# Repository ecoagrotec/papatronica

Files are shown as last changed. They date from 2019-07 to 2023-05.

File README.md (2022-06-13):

# papatronica

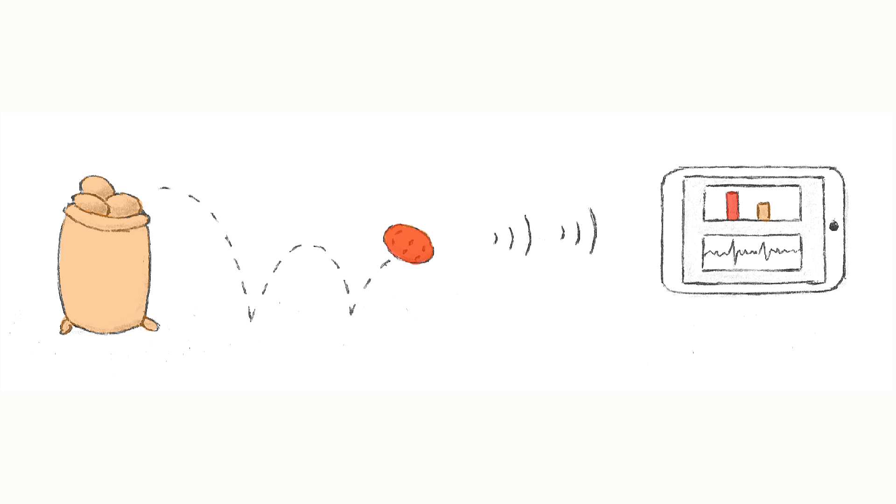
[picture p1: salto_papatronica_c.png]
papatronica


**papatronica** es un dispositivo abierto y modular diseñado para ser utilizado en el proceso de producción, cosecha, industrialización, comercialización y distribución de papa y con posible aplicación también en otros frutos y hortalizas. 

El objetivo general de Papatronica es poner a disposición de pequeños y medianos productores así como de toda la cadena de valor de producción de papa ( y de vegetales y hortalizas en general) una plataforma abierta y modular de código abierto y bajo costo que permita determinar los procesos o puntos específicos dentro de un proceso, donde se producen golpes, daños mecánicos y condiciones ambientales que afecten el estado y la conservación de los productos. Esto disminuirá significativamente las pérdidas de productos que se producen después de la cosecha (aproximadamente del 35% de las frutas y hortalizas producidas).
Esta plataforma, en principio se desarrollará orientada al uso en el cultivo de papa, pero será fácilmente adaptable a otros cultivos o productos.
 
## Objetivos específicos: 

- Medir los golpes que reciben los productos durante la cosecha, traslado, almacenamiento y comercialización.

- Ajustar la configuración ideal de las máquinaria para una producción libre de golpes.

- Investigar en forma objetiva los motivos del daño del producto por fuerzas de impacto en maquinaria, traslado y almacenamiento.

- Registrar y documentar la información para el cumplimiento de los procedimientos de control de calidad.

- Mejorar el diseño de maquinaria identificando los niveles de impacto.

- Ayudar a los productores y asesores a configurar sus máquinas para evitar altos niveles de impacto.

- Investigar enfoques de manejo técnico que minimicen los niveles de impacto en las papas.

- Determinar los umbrales para el riesgo de daño a las papas debido a la fuerza de impacto

- Investigar diferentes materiales que podrían reducir el riesgo de daños a las papas

Los productores, las industrias, la cadena comercial y los consumidores serían beneficiarios directos de este dispositivo.

### Perspectivas a futuro: 
 “papatronica” podría medir y registrar desde la plantación; temperatura, humedad, conductividad eléctrica y ph en el suelo. Se cosechará junto con el resto del lote y registrará toda la información durante la cosecha, el traslado y el almacenamiento, donde también medirá CO2 (y posiblemente otros gases). También podría transmitir toda la información en tiempo real permitiendo un seguimiento permanente y en tiempo real de las condiciones de los tubérculos desde la plantación hasta el punto final de comercialización.

### Requerimientos funcionales y estructurales del prototipo básico:

- La carcasa externa debe ser de forma oval alargada (similar a una papa), con un tamaño aproximado de 10 cm de largo, 8 de ancho y 7 de espesor; y suficientemente resistente para soportar aproximadamente 100 Kg de presión y caídas de hasta 2 m de altura. 

- La carcasa debe ser hermética para evitar el ingreso de polvo y agua, pero a su vez, debe ser posible abrir la misma para modificar o reemplazar componentes.

- La carcasa debe contener todos los componentes del dispositivo en forma segura y firme; pero a su vez debe permitir que los mismos sean retirados o reemplazados.
 
- La información registrada por los sensores deberá ser enviada al dispositivo de lectura (celular o tablet) en tiempo real a una distancia de aproximadamente 10 m. 

- La información debe ser simplificada visualizada en forma  “amigable con el usuario”

## Roadmap
1. definir componentes
2. presupuestar: componentes, desarrollo de app, diseño y construcción
3. búsqueda de financiamiento
4. compra de materiales y armado de prototipos
5. pruebas de campo y validación

*actualmente estamos en las etapas 3, 4 y 5 (ver la lista de [tareas/issues](https://github.com/ecoagrotec/papatronica/issues))*

Este es un proyecto de hardware abierto y se aceptan todo tipo de sugerencias, aportes y contribuciones (por ejemplo respondiendo a alguno de los _['issues'](https://github.com/ecoagrotec/papatronica/issues)_, abriendo algún nuevo _issue_, o mandándonos un mail con tus comentarios). 

Participantes del proyecto: 
- Luciano Velázquez
- Gustavo Pereyra Irujo
- Franco Pérez
- José Marone
- Ignacio Lalloz

Contacto:
luchovelazquez@gmail.com
gpereyrairujo@gmail.com

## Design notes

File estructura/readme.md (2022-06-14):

## Estructura de la Papatrónica

La estructura está realizada mediante impresión 3D en polímero de Nylon 6, utilizando una temperatura de extrusión de 235 °C y una temperatura de la cama de impresión de 110 °C. Está diseñada en 2 mitades simétricas complementarias, con una placa en la parte media sobre la cual se sujetan los componentes; y unidas por tornillos con tuercas.

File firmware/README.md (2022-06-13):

Pasos para cargar el programa en la placa NodeMCU:
1. Descargar el archivo papatronica.ino
2. Instalar el software Arduino IDE (descargar de https://www.arduino.cc/en/Main/Software)
3. Instalar desde el repositorio las librerias de espressif (chequear si son estas: https://github.com/espressif/arduino-esp32/tree/master/libraries)
4. Conectar la placa mediante un cable USB
5. Enviar el programa a la placa, presionando a la vez el botón "IO0" de la placa

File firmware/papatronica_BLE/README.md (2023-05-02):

  Firmware Papatronica BLE 
  Para la siguiente configuración de hardware/software:
  - Placa Adafruit Feather Bluefruit LE -> Bluefruit LE Connect app
  - Sensor Adafruit ADXL375

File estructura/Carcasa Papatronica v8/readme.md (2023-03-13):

La unica modificacion con respecto a la version 7 es que esta version se puede imprimir sin soportes.
Para lograr esto se usan puentes de 4cm max, si la impresora que se usa no soporta puentes de ese tamaño se recomienda usar soportes.

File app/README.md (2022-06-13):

El prototipo inicial de interfaz para el usuario que se está utilizando para las pruebas de la Papatrónica se desarrolló usando la app Android "RoboRemoFree" (https://www.roboremo.com/), que permite conectarse mediante Bluetooth a la placa nodeMCU, y editar fácilmente los elementos a mostrar en la pantalla.

Instrucciones para instalar la app y la interfaz:
1. Descargar la última versión del archivo UI-papatronica en el teléfono, desde https://github.com/ecoagrotec/papatronica/tree/master/app
2. Instalar la aplicación "RoboRemoFree" desde el Play Store de Android
3. Abrir la app
4. Ir a menu > interface > import
5. Seleccionar el archivo UI-papatronica

Instrucciones para utilizar la app con la papatronica:
1. Abrir la app y encender la papatronica
2. Ir a menu > connect
3. Seleccionar de la lista a papatronica

Instrucciones para modificar la interfaz:
1. Ir a menu > edit ui
2. Hacer los cambios
3. Para guardar los cambios en un archivo ir a menu > interface > export

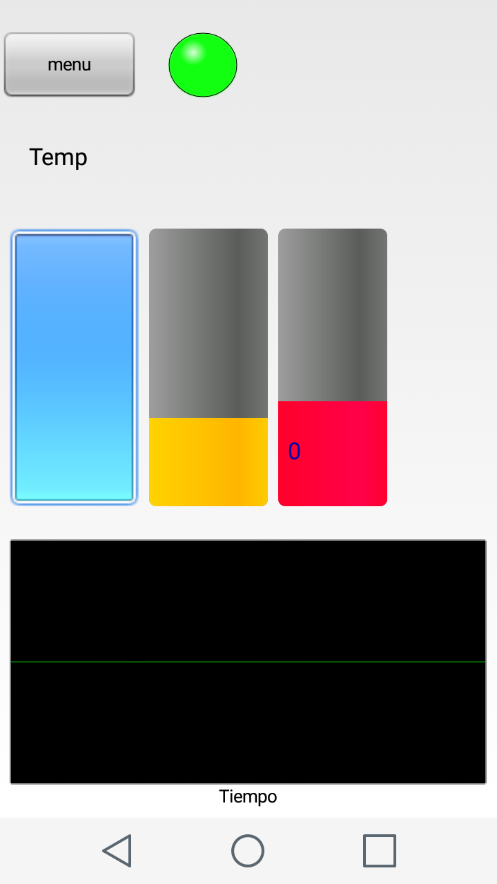
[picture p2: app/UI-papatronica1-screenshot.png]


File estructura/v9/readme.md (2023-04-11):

Esta nueva version esta echa en Fusion360. Ademas de los STLs subo el diseño completo y editable en Fusion360(.f3z). El tamaño del archivo .f3z es muy grande para github, estoy buscando alternativas para compartirlo.
Tiene algunos cambios menores con respecto a la v8.

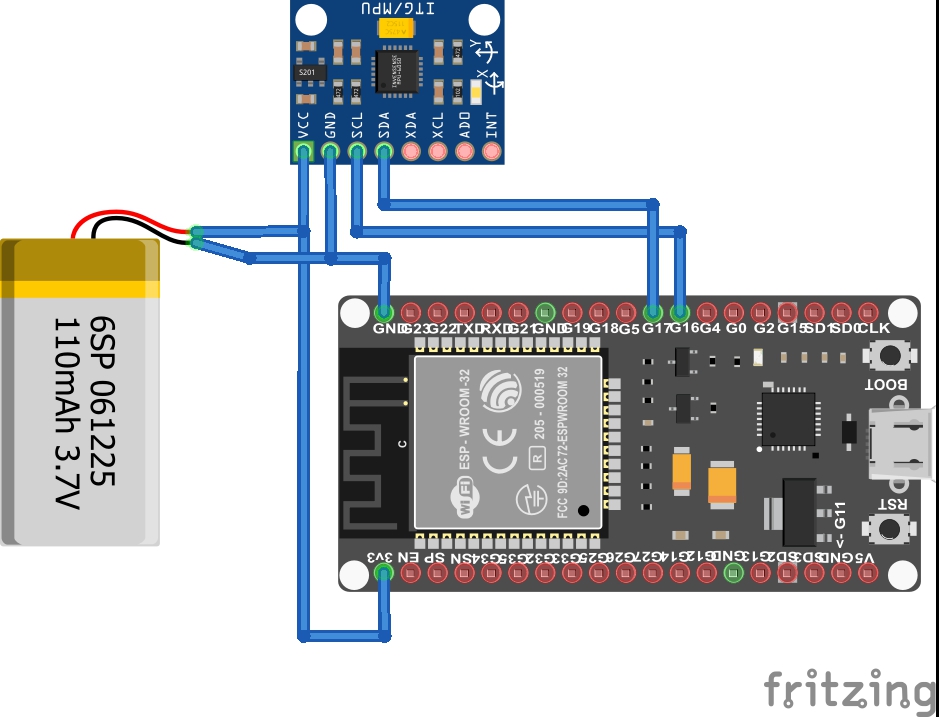
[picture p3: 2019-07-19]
electronica/papatronica.jpg

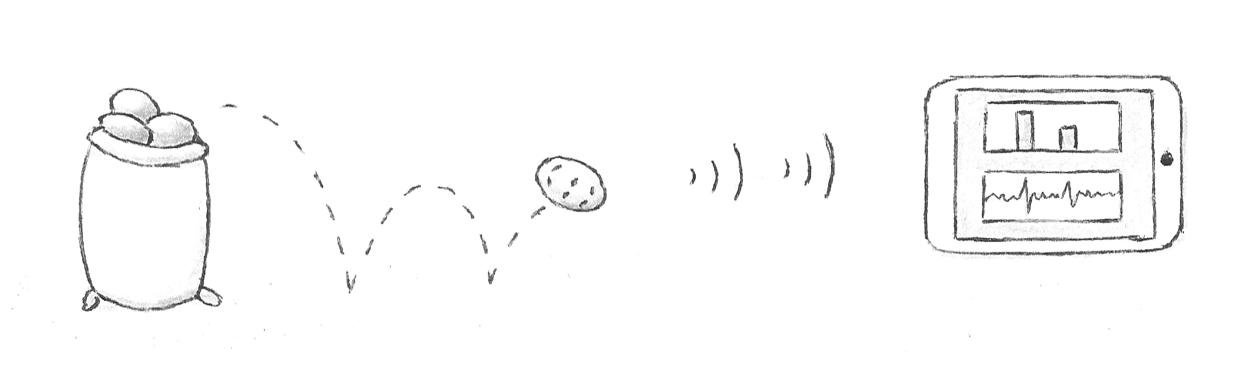
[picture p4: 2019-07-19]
salto_papatronica.png

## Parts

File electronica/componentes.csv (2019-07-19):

Componente | Nombre | Modelo
1 | Acelerómetro+giróscopo | MPU-6500
2 | Placa principal | NodeMCU Wifi+Bluetooth ESP32S
3 | Batería | Litio-Polímero 3.7V 500mAh

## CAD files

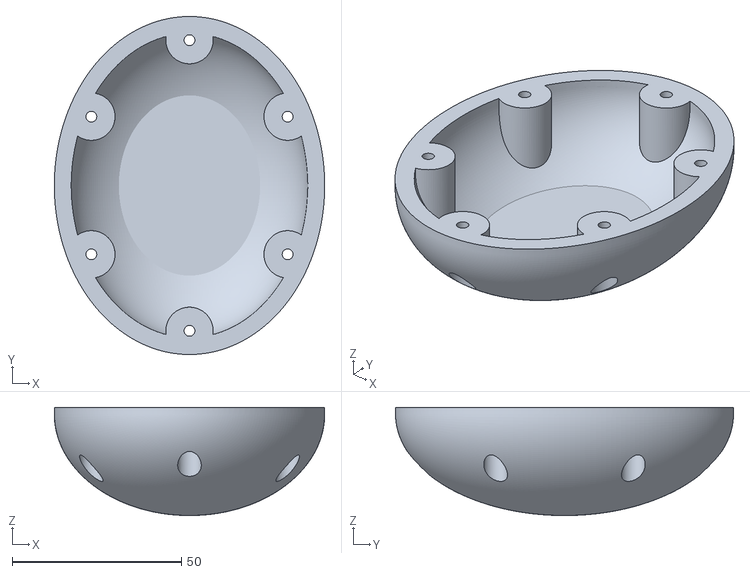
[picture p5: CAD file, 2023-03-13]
estructura/Carcasa Papatronica v8/v8 - Carcasa Papatronica - Mitad Tornillos.STL
80.0 x 100.0 x 32.0

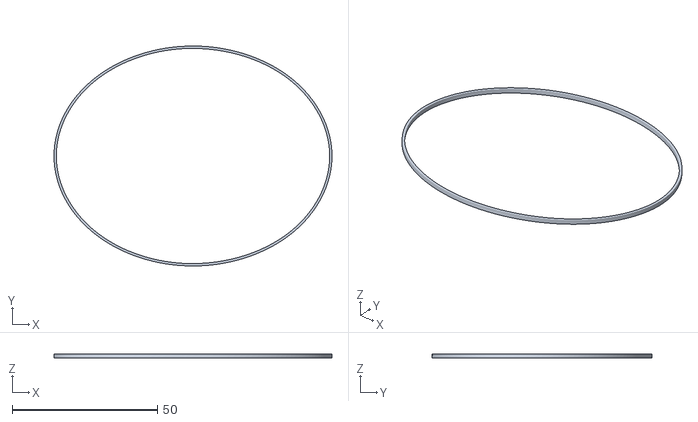
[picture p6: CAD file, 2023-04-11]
estructura/v9/Papatronica - Oring v9.stl
95.8 x 75.8 x 1.50

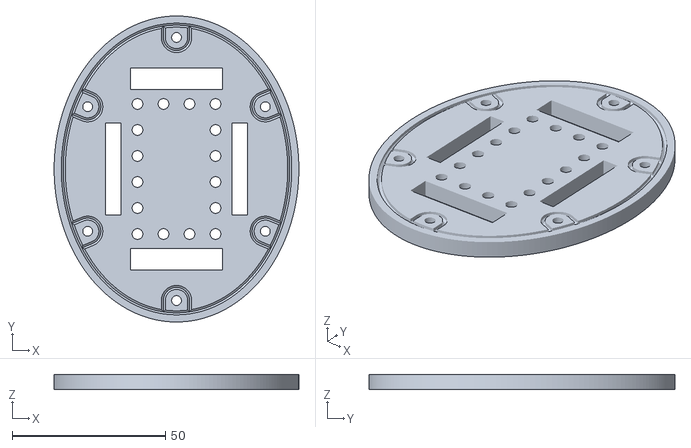
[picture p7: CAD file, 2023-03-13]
estructura/Carcasa Papatronica v8/v8 - Carcasa Papatronica - Rejilla.STL
80.0 x 100.0 x 5.00

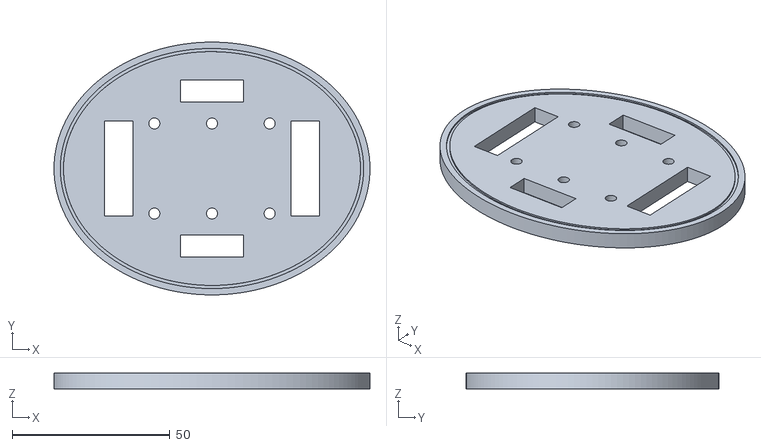
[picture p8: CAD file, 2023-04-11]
estructura/v9/Papatronica - Plate v9.stl
100.0 x 80.0 x 5.00

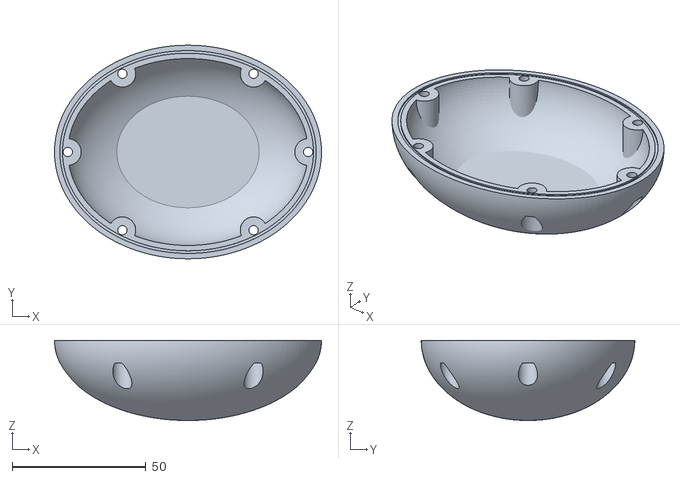
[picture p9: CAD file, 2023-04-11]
estructura/v9/Papatronica - Case-Bolt v9.stl
100.0 x 80.0 x 30.0

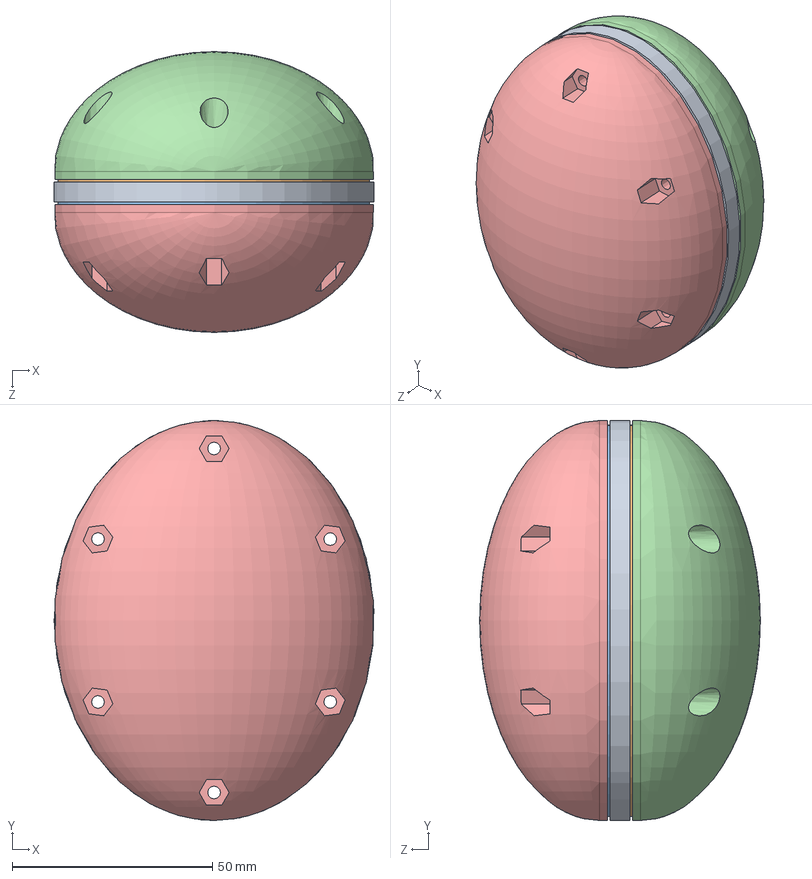
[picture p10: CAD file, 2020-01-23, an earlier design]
estructura/Carcasa Papatronica v7/v7 - Carcasa Papatronica - Ensamble Completo.SLDASM
79.9 x 100.0 x 70.2 mm
v7 - Carcasa Papatronica - Rejilla
v7 - Carcasa Papatronica - ORing
Copy of MirrorORing^v7 - Carcasa Papatronica - Ensamble Completo
v7 - Carcasa Papatronica - Mitad Tornillos
v7 - Carcasa Papatronica - Mitad Tuercas

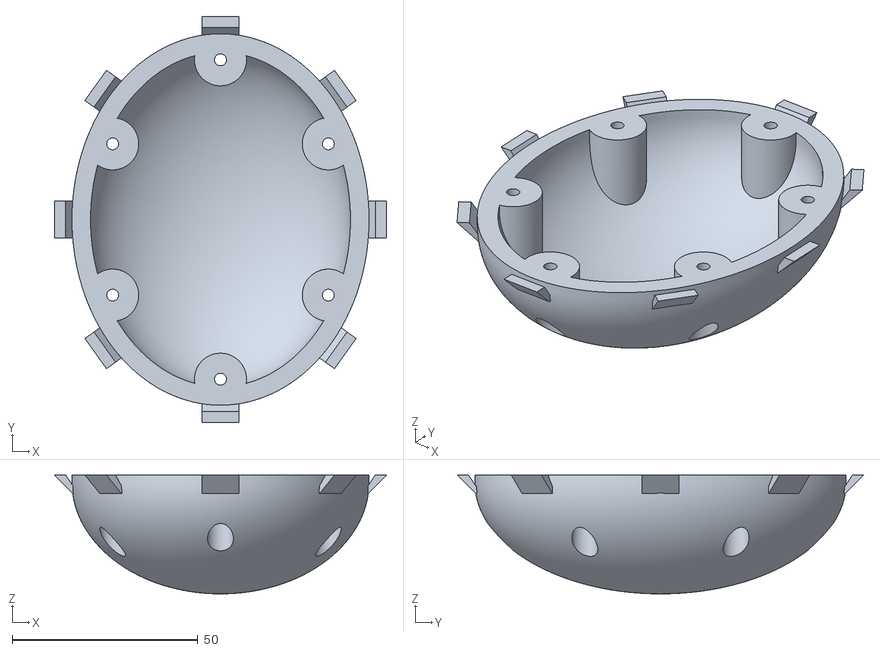
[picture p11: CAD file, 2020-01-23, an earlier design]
estructura/Carcasa Papatronica v7/STL y Gcode/v7 - Carcasa Papatronica - Mitad Tornillos.STL
89.4 x 109.4 x 32.0

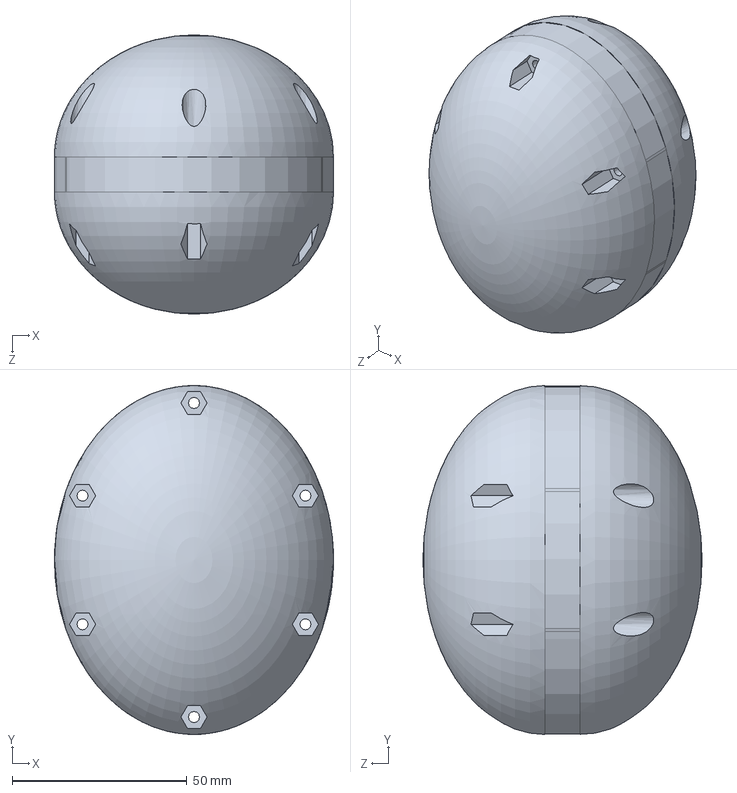
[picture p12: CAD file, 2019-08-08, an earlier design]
estructura/v5/Carcaza Papa.SLDPRT
80.0 x 100.0 x 80.0 mm

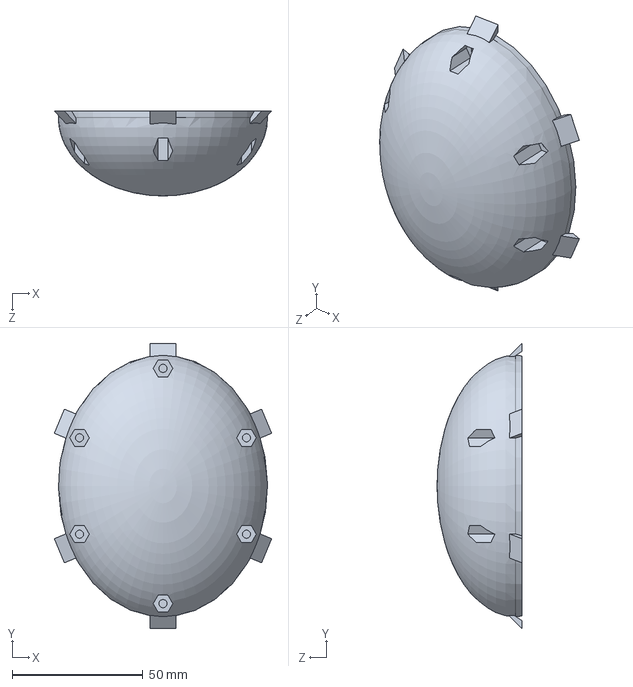
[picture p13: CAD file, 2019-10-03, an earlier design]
estructura/v6/v6 - Carcaza Papa - MH.sldprt
83.1 x 109.0 x 32.5 mm

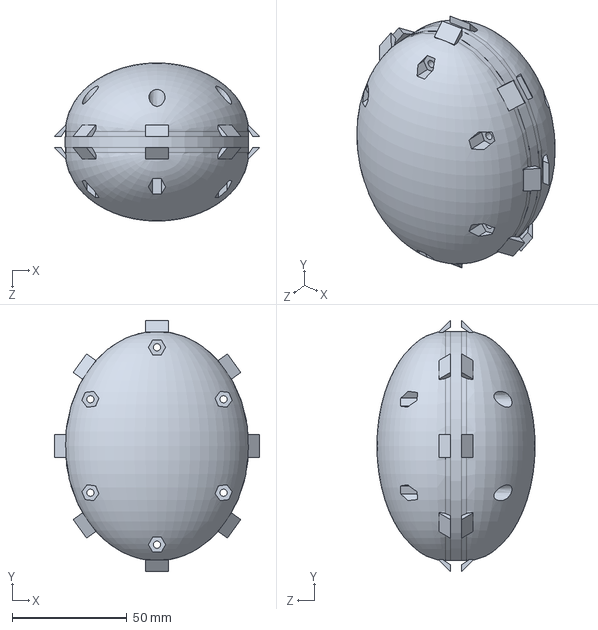
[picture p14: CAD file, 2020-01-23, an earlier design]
estructura/Carcasa Papatronica v7/v7 - Carcasa Papatronica.SLDPRT
89.4 x 109.4 x 69.0 mm

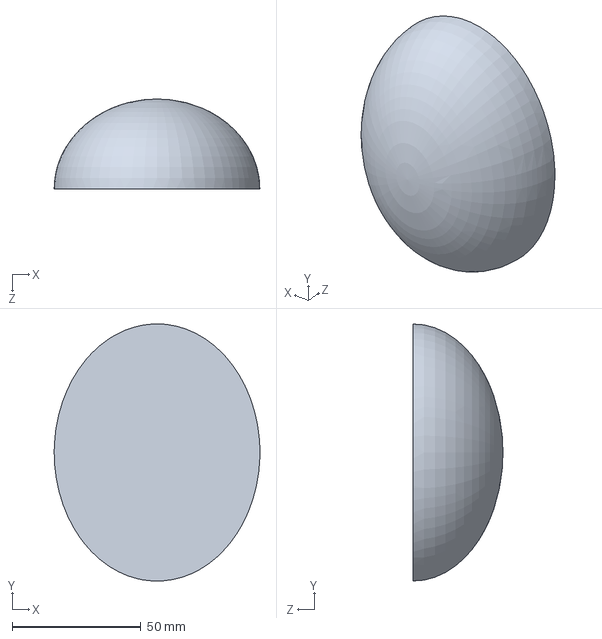
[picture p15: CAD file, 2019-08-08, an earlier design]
estructura/v5/Carcaza Papa - Split 1 - 2.sldprt
80.0 x 99.9 x 35.0 mm

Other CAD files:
estructura/poliedrica/carcasa-tornillos-poliedrica.stl
estructura/poliedrica/carcasa-tuercas-poliedrica.stl
estructura/Carcasa Papatronica v8/v8 - Carcasa Papatronica - Mitad Tuercas.STL
estructura/v9/Papatronica - Case-Nut v9.stl
estructura/Carcasa Papatronica v7/v7 - Carcasa Papatronica - Mitad Tornillos.sldprt
estructura/Carcasa Papatronica v7/STL y Gcode/v7 - Carcasa Papatronica - Rejilla.STL
estructura/v6/v6 - Carcaza Papa - MR.sldprt
estructura/Carcasa Papatronica v7/STL y Gcode/v7 - Carcasa Papatronica - Mitad Tuercas.STL
estructura/Carcasa Papatronica v7/v7 - Carcasa Papatronica - Mitad Tuercas.sldprt
estructura/Carcasa Papatronica v7/v7 - Carcasa Papatronica - ORing.SLDPRT
estructura/Carcasa Papatronica v7/v7 - Carcasa Papatronica - Rejilla.sldprt
estructura/v5/Carcaza Papa - MH.STL
estructura/v5/Carcaza Papa - MH.sldprt
estructura/v5/Carcaza Papa - MR.SLDPRT
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

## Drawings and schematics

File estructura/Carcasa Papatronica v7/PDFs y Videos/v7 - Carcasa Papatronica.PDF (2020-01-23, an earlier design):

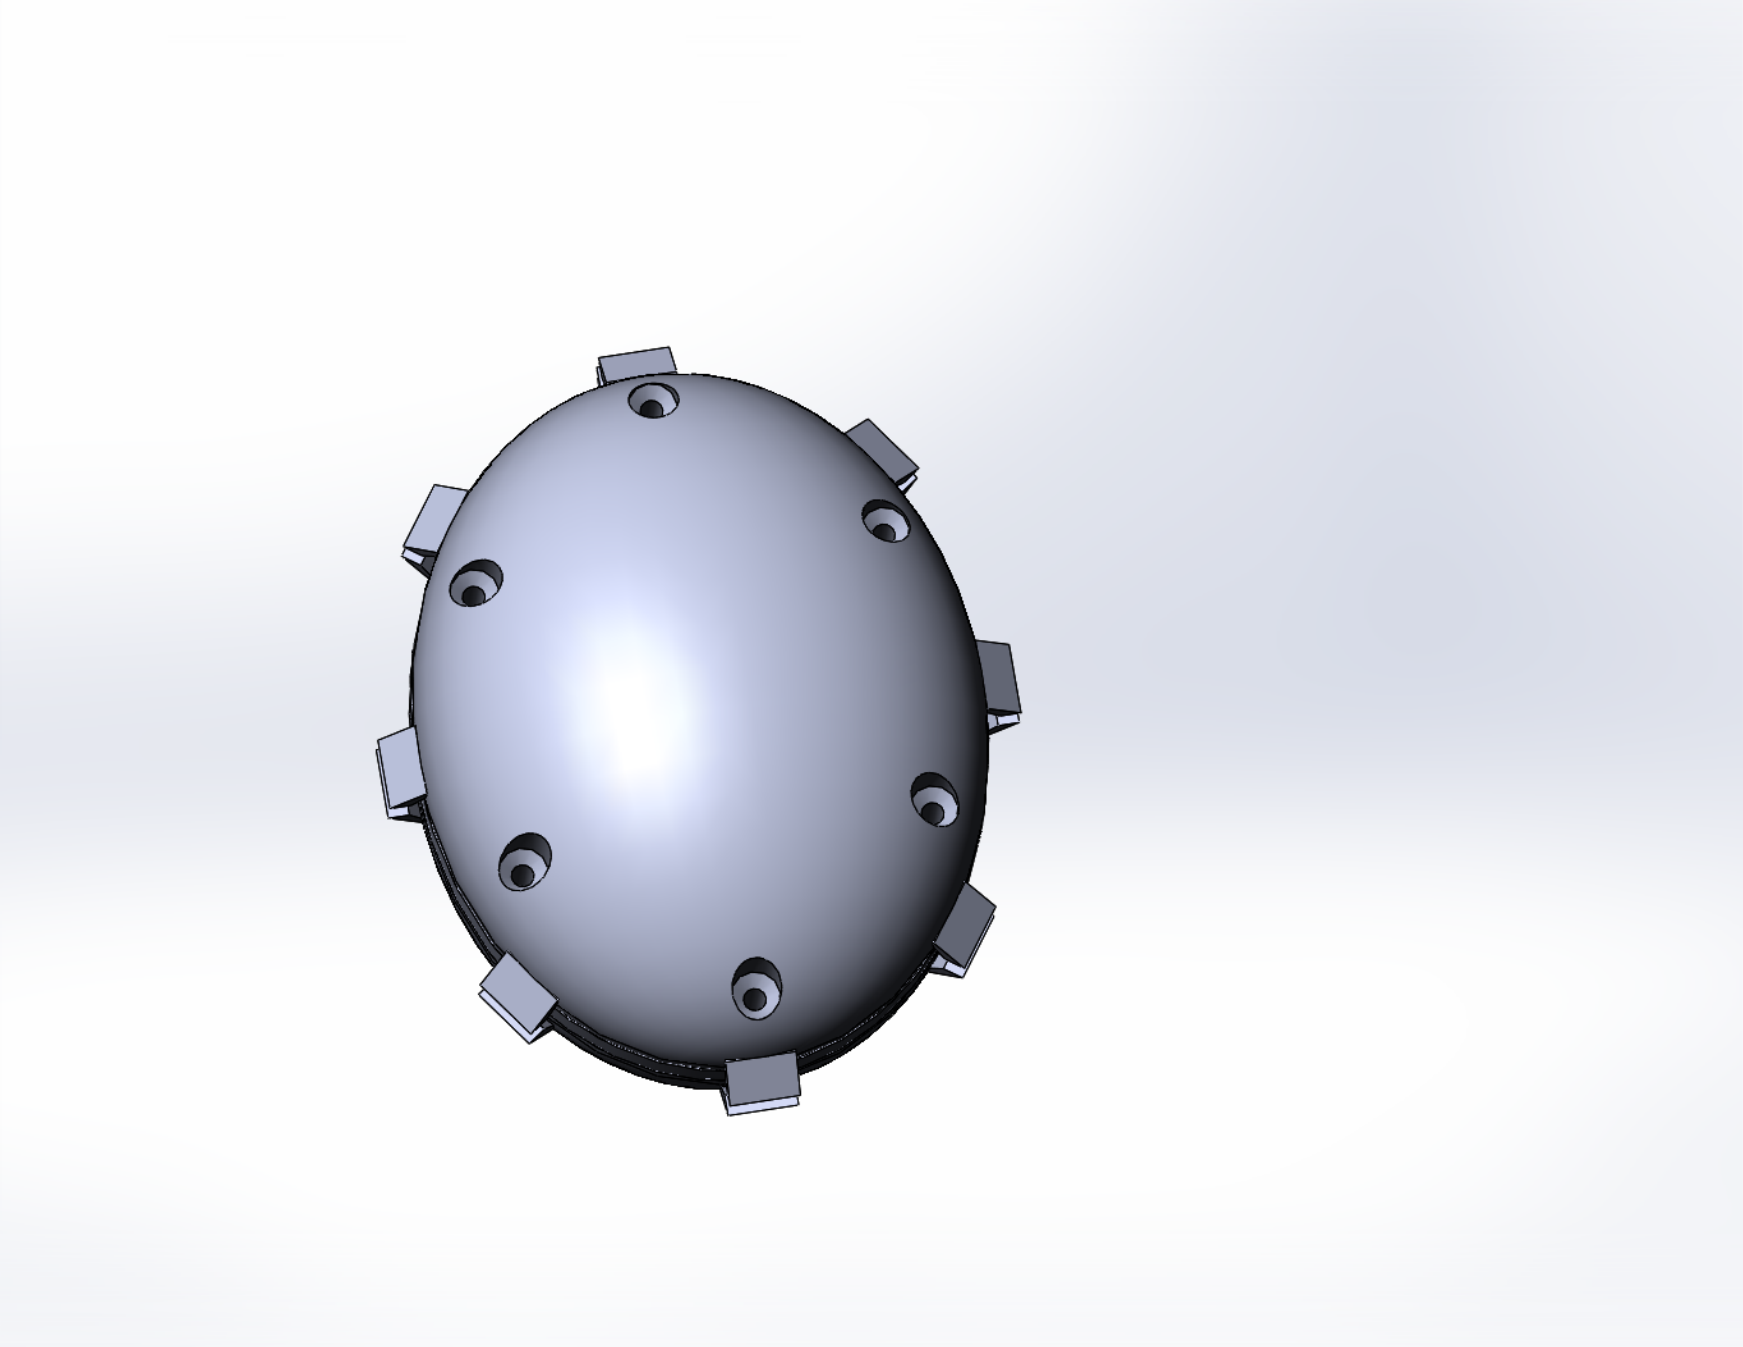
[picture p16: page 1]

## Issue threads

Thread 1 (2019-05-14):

Definir componentes: placa principal

gpereyrairujo, 2019-05-14:
Para la placa principal (el 'cerebro') nos parece conveniente utilizar una placa Arduino (arduino.cc), ya que son baratas, fáciles de conseguir, y existe en internet mucha información y ejemplos de uso. Existen varios modelos distintos de placas Arduino, con distintos tamaños y distintas funciones. El modelo más común es el Arduino UNO, pero sería muy grande para este proyecto.  Existen otros modelos más pequeños, con distintas características, por ejemplo:
- Arduino Pro Mini
- Arduino Nano
- Arduino Micro
- Arduino MKR1000
Habría que evaluar las ventajas y desventajas de cada uno de los modelos, o proponer otros.

gpereyrairujo, 2019-05-18:
Se acaba de publicar una nueva versión de la placa Arduino Nano, con ya trae incorporados bluetooth (#4 ), acelerómetros (#2), sensor de temperatura, etc. (https://store.arduino.cc/usa/nano-33-ble-sense-with-headers). No está disponible aún, pero quizás sea una buena opción empezar con la placa Arduino Nano 'común', para que luego sea fácil hacer la transición al nuevo modelo.

gpereyrairujo, 2019-05-23:
Otra opción interesante son las placas Adafruit Feather (https://learn.adafruit.com/adafruit-feather/overview), que traen incorporado un circuito de carga de baterías LiPo (solucionaría el issue #3) y en algunos modelos también incorpora Bluetooth LE (solucionaría el issue #4).

gpereyrairujo, 2019-05-23:
Por ejemplo:
- [Adafruit Feather Nrf52 Bluefruit LE](https://articulo.mercadolibre.com.ar/MLA-746389139-placa-adafruit-feather-nrf52-bluefruit-le-nrf52832-_JM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)
- [Adafruit Feather M0 Bluefruit LE](https://articulo.mercadolibre.com.ar/MLA-746389130-placa-de-desarrollo-adafruit-feather-m0-bluefruit-le-_JM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)

lucianovelazquez, 2019-06-05:
Se utilizará la placa Adafruit Feather M0 Bluefruit LE

https://articulo.mercadolibre.com.ar/MLA-746389130-placa-de-desarrollo-adafruit-feather-m0-bluefruit-le-_JM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

lucianovelazquez, 2019-06-07:
Nodemcu https://articulo.mercadolibre.com.ar/MLA-631798449-nodemcu-v3-lua-esp8266-wifi-iot-gpio-pwm-i2c-arduino-pdiy--_JM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

lucianovelazquez, 2019-06-21:
Ignacio ya probó un node mcu con wifi y logró conectarlo con el acelerómetro mpu6050 y megir aceleración y temperatura mediante la conexión por USB.  Próximamente recibirá el node mcu ESP32  que tiene Wifi y bluetooth y realizará pruebas de conectividad por wifi y bluetooth.

josemarone, 2019-07-19:
Este es el esquemático y pinout de la placa ESP32s https://docs.zerynth.com/latest/official/board.zerynth.nodemcu_esp32/docs/index.html

lucianovelazquez, 2019-07-19:
Programación de la placa: descargar el archivo y https://github.com/ecoagrotec/papatronica/blob/master/firmware/mpu6050esp32.ino
Para correrlo, instalar (desde el repositorio) las librerías de espressif en el entorno que usen

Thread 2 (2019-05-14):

Definir componentes: acelerómetro

gpereyrairujo, 2019-05-14:
Para medir los golpes recibidos es necesario un sensor que mida la des-aceleración que se produce al caer la 'papa'. Este tipo de sensores se denominan acelerómetros, y son los mismos que están presentes en los teléfonos celulares para poder detectar la orientación de la pantalla, o en algunos discos rígidos para apagarse ante una caída.
Existen distintos tipos de acelerómetros, que también pueden estar combinados con giroscopios y brújulas para una estimación completa de la posición en el espacio (https://www.sparkfun.com/pages/accel_gyro_guide).
Habría que definir qué modelo de acelerómetro sería más adecuado para este proyecto.

vuelaendron, 2019-05-22:
Algunos datos:
- La placa NAZE32 que usamos como primer prototipo tiene el chip acelerómetro/giróscopo MPU6500, con sensibilidad de hasta 16g (vienen módulos para Arduino con ese chip, aprox $400)
- La nueva placa Arduino Nano Sense (ver issue #1) trae el chip LSM9DS1, también con sensibilidad de 16g (también viene como un módulo, aprox $1900, y funciona a 3.3v)
- Hay acelerómetros con un rango de 200g de aceleración, como el ADXL377, o de 24g como el LIS331 (Sparkfun tiene modelos de módulos para Arduino, pero no parecen conseguirse en Argentina)

gpereyrairujo, 2019-05-22:
Algunos datos:
- La placa NAZE32 que usamos como primer prototipo tiene el chip acelerómetro/giróscopo MPU6500, con sensibilidad de hasta 16g (vienen módulos para Arduino con ese chip, aprox $400)
- La nueva placa Arduino Nano Sense (ver issue #1) trae el chip LSM9DS1, también con sensibilidad de 16g (también viene como un módulo, aprox $1900, y funciona a 3.3v)
- Hay acelerómetros con un rango de 200g de aceleración, como el ADXL377, o de 24g como el LIS331 (Sparkfun tiene modelos de módulos para Arduino, pero no parecen conseguirse en Argentina)

lucianovelazquez, 2019-06-05:
El acelerómetro podría ser el adxl 345

https://articulo.mercadolibre.com.ar/MLA-664066432-modulo-acelerometro-de-3-ejes-con-adxl345-arduino-pic-arm-_JM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

lucianovelazquez, 2019-06-07:
https://www.analog.com/media/en/technical-documentation/data-sheets/ADXL345.pdf

Diferencias con MPU: https://www.invensense.com/wp-content/uploads/2015/02/PS-MPU-9250A-01-v1.1.pdf

gpereyrairujo, 2019-06-07:
en la reunión de hoy (luciano, jorge, ignacio, gustavo) hablamos que dada la poca diferencia de precio, sería conveniente usar un módulo con acelerómetro y giróscopo (6 ejes) en lugar de uno con sólo acelerómetro (3 ejes).

con acelerómetro y giróscopo se podría contar con mejor información de los movimientos y (al menos en teoría) evitar el error observado en las 'papas electrónicas' comerciales que detectan supuestos golpes cuando hay un movimiento solamente de rotación.

podríamos probar el MPU6500 (el mismo de la placa NAZE), que está disponible en argentina (https://articulo.mercadolibre.com.ar/MLA-752867801-acelerometro-giroscopo-gy-6500-mpu-6500-3-ejes-emakers-_JM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). también hay uno similar, el MPU6050, para el cual pareciera haber más ejemplos de uso para arduino. es más barato (https://articulo.mercadolibre.com.ar/MLA-750881333-acelerometro-3-ejes-mpu6050-giroscopio-arduino-emakers-_JM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), y la diferencia parece ser que la comunicación es solo mediante el protocolo I2C (más lento), a diferencia del MPU6500 que también podría usar el protocolo SPI (más rápido; https://blog.dronetrest.com/inertial-sensor-comparison-mpu6000-vs-mpu6050-vs-mpu6500-vs-icm20602/).

lucianovelazquez, 2019-06-21:
Ignacio compró el acelerómetro mpu6500 (GY-521)

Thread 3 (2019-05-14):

Definir componentes: batería

gpereyrairujo, 2019-05-14:
Este proyecto requiere el uso de una batería. Existen distintas opciones, tales como pilas 'comunes' (AA o AAA), pilas 'de reloj', o pilas recargables (por ejemplo de litio-polímero, o LiPo). Esto va a depender del consumo, del tipo de placa principal que se use (qué voltaje de entrada admiten, si tienen o no circuito para cargar baterías recargables), y de otras cuestiones (necesidad de abrir para cambiar la batería o no).
Habría que definir qué batería es la más conveniente para el proyecto.

lucianovelazquez, 2019-06-05:
La batería podría ser: Bateria Lipo Con Cable Jst-ph 3.7v 500mah

https://articulo.mercadolibre.com.ar/MLA-711869674-bateria-lipo-con-cable-jst-ph-37v-500mah-drones-_JM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

lucianovelazquez, 2019-06-21:
Ignacio sugiere que 500 mah es poco para wifi. Habría que apuntar a una batería de 2000 mah aprox.

lucianovelazquez, 2019-08-07:
Se probó la autonomía de la batería cargando la misma (LiPo de 3.7V y 500 mAh) hasta 4,2 V y observando la actividad del dispositivo (toma y envío de datos por bluetooth al dispositivo Android. Se registró un correcto funcionamiento hasta 3,2V dando una autonomía de 27 horas.

josemarone, 2019-09-04:
Hay que sumar un Step down para tener alimentación constante como este: https://articulo.mercadolibre.com.ar/MLA-756238158-fuente-dc-dc-step-up-down-boost-18v-5v-150ma-33v-mona-_JM

josemarone, 2020-01-29:
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

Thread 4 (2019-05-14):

Definir componentes: comunicación

gpereyrairujo, 2019-05-14:
Para complir su función, la papatrónica debe ser capaz de transmitir las mediciones en tiempo real de forma inalámbrica. Esto se podría hacer mediante una conexión Bluetooth (o BLE, Bluetooth Low Energy) o WiFi. Qué sistema se elije puede incidir en el consumo de energía, y también en la distancia a la cual se pueden recibir los datos.
Habría que decidir qué sistema de comunicación es más conveniente para el poryecto.

lucianovelazquez, 2019-05-26:
Respecto al alcance de la comunicación, el requerimiento mínimos son un alcance de 10 m (sufieciente para realizar las regulaciones básicas para reducción de golpes; pero pero pensando en posibles aplicaciones durante el almacenamiento y la comercialización, sería conveniente tener un alcance cercano a los 50m. También hay que evaluar la pérdida de comunicación por la barreras físicas (por ejemplo que el dispositivo quede en el fondo de una pila de papas.

lucianovelazquez, 2019-06-05:
Quedaría resuelto con la placa

lucianovelazquez, 2019-06-21:
Conectividad por wifi y sockets.
Wifi tendría una autonomía de aprox 9 Hs .
Posibilidad de conectar el wifi cada determinado tiempo, enviar datos y desconectarse (tipo timer / RTC).

josemarone, 2019-08-16:
Buena descripción de los diferentes tipos de Bluetooth, https://randomnerdtutorials.com/esp32-bluetooth-low-energy-ble-arduino-ide/

juanmaone, 2019-09-26:
Para mayor alcance, y bajo consumo, hay módulos esp32  con Lora, muy recomendables

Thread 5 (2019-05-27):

Definir componentes: estructura

lucianovelazquez, 2019-05-27:
Evaluar la posibilidad de imprimir la estructura mediante impresión 3D y definir qué polímero sería el más adecuado para soportar las condiciones ambientales, los golpes y presiones a los que será sometido el dispositivo.

lucianovelazquez, 2019-05-31:
Sergio y Franco sugirieron la posibilidad de imprimir la estructura en Nylon; y de acuerdo a las siguientes revisiones, tiene alta resistencia y durabilidad y una capacidad de deformación media. ,

https://all3dp.com/1/3d-printer-filament-types-3d-printing-3d-filament/

https://www.simplify3d.com/support/materials-guide/properties-table/

lucianovelazquez, 2019-06-05:
El filamento de Nylon podría ser:

 https://articulo.mercadolibre.com.ar/MLA-777582920-filamento-nylon6-175mm-grilon3-1kg-impresora-3d-colores-_JM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

lucianovelazquez, 2019-06-21:
Franco va a realizar un primer diseño de la estructura para después hacer la impresión 3D.

lucianovelazquez, 2019-07-01:
Nuevo diseño de estructura. Reja en el medio para sujetar todos los componentes.

lucianovelazquez, 2019-07-19:
Archivos de diseño e impresión de la estructura

https://drive.google.com/drive/folders/1nzFkk9vt94vcJgs3z7Mc66_alWa3HSfu?usp=sharing

lucianovelazquez, 2019-08-09:
pruebade impresión de nueva versión de la carcasa (carpeta V5). Tempertura de cama 110 y Temperatura de extrusor 240.

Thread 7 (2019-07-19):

Cómo conectar la batería al nodeMCU

gpereyrairujo, 2019-07-19:
En el prototipo actual, la batería lipo de 3.7V está conectada directamente a los pines 3V3 y GND (a través del acelerómetro), como en este esquema:

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

Habría que chequear si esta conexión es correcta, ya que el voltaje de la batería varía entre 4.2V cuando está cargada hasta 3.3V o menos cuando está descargada.

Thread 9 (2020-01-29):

prototipo interfaz app android

gpereyrairujo, 2020-01-29:
Se está probando el prototipo de interfaz para el usuario usando una app android llamada "RoboRemoFree" (https://www.roboremo.com/), que permite conectarse mediante bluetooth a la placa nodeMCU, y editar fácilmente los elementos a mostrar en la pantalla.

Las instrucciones para instalar la app y la interfaz para la papatronica están en la carpeta 'app' del repositorio

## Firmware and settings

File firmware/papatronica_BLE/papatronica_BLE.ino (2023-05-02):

/*********************************************************************
  Firmware Papatronica BLE 
  Para la siguiente configuración de hardware/software:
  - Placa Adafruit Feather Bluefruit LE -> Bluefruit LE Connect app
  - Sensor Adafruit ADXL375

  Proyecto Papatronica
  https://github.com/ecoagrotec/papatronica
  
  Licencia CERN-OHL-S
  https://ohwr.org/cern_ohl_s_v2.txt
*********************************************************************/


// Código BLE - Adafruit Feather Bluefruit LE
// Adaptado de: https://github.com/adafruit/Bluefruit_LE_Connect_Plotter
// MIT License
/*********************************************************************
  Bluefruit LE Connect Plotter 
  for Feather Bluefruit -> Bluefruit LE Connect app
  
  outputs dummy values for demo use with BLuefruit LE Connect app
  change SEND_SECOND_PLOT define to 1 to output second plot using sine wave table

  Adafruit invests time and resources providing this open source code,
  please support Adafruit and open-source hardware by purchasing
  products from Adafruit!

  MIT license, check LICENSE for more information
  All text above, and the splash screen below must be included in
  any redistribution
*********************************************************************/

// Código sensor ADXL375
// Adaptado de: https://learn.adafruit.com/adafruit-adxl375/arduino
// BSD License - https://github.com/adafruit/Adafruit_ADXL375/blob/master/license.txt

// Código para medir voltaje de batería
// Adaptado de: https://learn.adafruit.com/adafruit-feather-m0-bluefruit-le/power-management



// BLE - Adafruit Feather Bluefruit LE
#include <Arduino.h>
#include <SPI.h>
#if not defined (_VARIANT_ARDUINO_DUE_X_) && not defined (_VARIANT_ARDUINO_ZERO_)
#include <SoftwareSerial.h>
#endif
#include "Adafruit_BLE.h"
#include "Adafruit_BluefruitLE_SPI.h"
#include "Adafruit_BluefruitLE_UART.h"
#include "BluefruitConfig.h"

// ADXL375
#include <Wire.h>
#include <Adafruit_Sensor.h>
#include <Adafruit_ADXL375.h>
#define ADXL375_SCK 13
#define ADXL375_MISO 12
#define ADXL375_MOSI 11
#define ADXL375_CS 10
/* Assign a unique ID to this sensor at the same time */
/* Hardware SPI */
Adafruit_ADXL375 accel = Adafruit_ADXL375(ADXL375_CS, &SPI, 12345);

// batería
#define VBATPIN A7 


void displayDataRate(void)
{
  if (accel.getDataRate() == ADXL343_DATARATE_3200_HZ)
  {
      Serial.println("Tasa de muestreo correcta (3200 Hz)");
  } else {
      Serial.println("Tasa de muestreo incorrecta");
  }
}


/*=========================================================================
    APPLICATION SETTINGS

      FACTORYRESET_ENABLE       Perform a factory reset when running this sketch
     
                                Enabling this will put your Bluefruit LE module
                              in a 'known good' state and clear any config
                              data set in previous sketches or projects, so
                                running this at least once is a good idea.
     
                                When deploying your project, however, you will
                              want to disable factory reset by setting this
                              value to 0.  If you are making changes to your
                                Bluefruit LE device via AT commands, and those
                              changes aren't persisting across resets, this
                              is the reason why.  Factory reset will erase
                              the non-volatile memory where config data is
                              stored, setting it back to factory default
                              values.
         
                                Some sketches that require you to bond to a
                              central device (HID mouse, keyboard, etc.)
                              won't work at all with this feature enabled
                              since the factory reset will clear all of the
                              bonding data stored on the chip, meaning the
                              central device won't be able to reconnect.
    MINIMUM_FIRMWARE_VERSION  Minimum firmware version to have some new features
    MODE_LED_BEHAVIOUR        LED activity, valid options are
                              "DISABLE" or "MODE" or "BLEUART" or
                              "HWUART"  or "SPI"  or "MANUAL"
    -----------------------------------------------------------------------*/
#define FACTORYRESET_ENABLE         1
#define MINIMUM_FIRMWARE_VERSION    "0.6.6"
#define MODE_LED_BEHAVIOUR          "BLEUART" // el LED rojo titila cuando transmite datos por BLE - el led azul se enciende cuando hay una conexión establecida
#define SEND_SECOND_PLOT            0
/*=========================================================================*/

// Create the bluefruit object, hardware SPI, using SCK/MOSI/MISO hardware SPI pins and then user selected CS/IRQ/RST */
Adafruit_BluefruitLE_SPI ble(BLUEFRUIT_SPI_CS, BLUEFRUIT_SPI_IRQ, BLUEFRUIT_SPI_RST);

// A small helper
void error(const __FlashStringHelper*err) {
  Serial.println(err);
  while (1);
}

/**************************************************************************/
/*!
    @brief  Sets up the HW an the BLE module (this function is called
            automatically on startup)
*/
/**************************************************************************/
void setup(void)
{
  // initialize digital pin 13 as an output (LED)
  pinMode(13, OUTPUT);

  delay(500);

  Serial.begin(115200);
  Serial.println(F("Adafruit Bluefruit Command <-> Data Mode Example"));
  Serial.println(F("------------------------------------------------"));

  /* Initialise the module */
  Serial.print(F("Initialising the Bluefruit LE module: "));

  if ( !ble.begin(VERBOSE_MODE) )
  {
    error(F("Couldn't find Bluefruit, make sure it's in CoMmanD mode & check wiring?"));
  }
  Serial.println( F("OK!") );

  if ( FACTORYRESET_ENABLE )
  {
    /* Perform a factory reset to make sure everything is in a known state */
    Serial.println(F("Performing a factory reset: "));
    if ( ! ble.factoryReset() ) {
      error(F("Couldn't factory reset"));
    }
  }

  /* Disable command echo from Bluefruit */
  ble.echo(false);

  Serial.println("Requesting Bluefruit info:");
  /* Print Bluefruit information */
  ble.info();

  Serial.println(F("Please use Adafruit Bluefruit LE app to connect in UART mode"));
  Serial.println(F("Then Enter characters to send to Bluefruit"));
  Serial.println();

  ble.verbose(false);  // debug info is a little annoying after this point!

  /* Wait for connection */
  while (! ble.isConnected()) {
    delay(500);
  }

  Serial.println(F("* * * * *"));

  // LED Activity command is only supported from 0.6.6
  if ( ble.isVersionAtLeast(MINIMUM_FIRMWARE_VERSION) )
  {
    // Change Mode LED Activity
    Serial.println(F("Change LED activity to " MODE_LED_BEHAVIOUR));
    ble.sendCommandCheckOK("AT+HWModeLED=" MODE_LED_BEHAVIOUR);
  }

  // Set module to DATA mode
  Serial.println( F("Switching to DATA mode!") );
  ble.setMode(BLUEFRUIT_MODE_DATA);

  Serial.println(F("* * * * *"));

  // ADXL375
  Serial.println("ADXL375 Accelerometer Test"); Serial.println("");
  /* Initialise the sensor */
  if(!accel.begin())
  {
    /* There was a problem detecting the ADXL375 ... check your connections */
    Serial.println("Ooops, no ADXL375 detected ... Check your wiring!");
    while(1);
  }
  // Range is fixed at +-200g
  // Set data rate at 3200 Hz
  accel.setDataRate(ADXL343_DATARATE_3200_HZ);
  /* Display some basic information on this sensor */
  accel.printSensorDetails();
  displayDataRate();
  Serial.println("");

}


// ********************************************************************** //

float medicion = 0;
float max_medicion = 0;
float medicion_anterior = 0;
float umbral = 5;
unsigned long timeout = 200;
unsigned long last_timeout = millis ();
int mediciones_bajo_umbral = 0;

void loop(void) {

    /* Get a new sensor event */
    sensors_event_t event;
    last_timeout = millis ();
    max_medicion = 0;
    
    while (timeout > (millis () - last_timeout) ){
      accel.getEvent(&event); 
      medicion = sqrt( sq(event.acceleration.x) + sq(event.acceleration.y) + sq(event.acceleration.z) ) / 9.8;     // convertir a g
      if (medicion > max_medicion ){
        max_medicion = medicion;
      }
    }
   
    if (max_medicion < umbral) {
      mediciones_bajo_umbral += 1;
      float measuredvbat = analogRead(VBATPIN);
      measuredvbat = measuredvbat * 2 * 3.3 / 1024;   // convertir a volts
      measuredvbat = (measuredvbat - 3.45) / 0.7;  // convertir a un rango entre 0 y 1 aprox (entre 3.45V y 4.15V)
      if (mediciones_bajo_umbral < 300) {
        ble.println(measuredvbat);              // graficar voltaje de la batería
      } else if ((mediciones_bajo_umbral % 300) == 0) {
        ble.println(measuredvbat);              // graficar voltaje de la batería
      } 
    } else {
      ble.println(max_medicion);              // graficar valor máximo medido
      mediciones_bajo_umbral = 0;
    }
  
}

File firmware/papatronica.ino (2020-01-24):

#include <BluetoothSerial.h>
#include <MPU6050_tockn.h>
#include <Wire.h>

#if !defined(CONFIG_BT_ENABLED) || !defined(CONFIG_BLUEDROID_ENABLED)
#error Bluetooth is not enabled!
#endif


BluetoothSerial SerialBT;
MPU6050 mpu6050(Wire, 0.1, 0.9);

const uint8_t scl = 16;// Select SDA and SCL pins for I2C communication
const uint8_t sda = 17;
double MagnitudUmbral = 0.0 ;
double Magnitud = 0 ;
long timeL, timeS = 0;

float maximunAccMeasure = 3;
float redRange = 0.4;
float yelowAlarm = 0.4;
float greenRange = 0.4;
bool ledState = false;

double Ax, Ay, Az, aux_Magnitud ;
float IMU_Temperature;

void setup() {
  Serial.begin(115200);
  SerialBT.begin("PapaTronica"); //Bluetooth device name
  Wire.begin(sda, scl);
  mpu6050.begin();
  mpu6050.calcGyroOffsets(false);
  mpu6050.writeMPU6050(MPU6050_ACCEL_CONFIG, 0x30);
  mpu6050.writeMPU6050(MPU6050_PWR_MGMT_1, 0x01);
  mpu6050.update();
}

void loop()
{
  mpu6050.update();
  
  Ax = mpu6050.getAccX();
  Ay = mpu6050.getAccY();
  Az = mpu6050.getAccZ();
  aux_Magnitud = std::abs(sqrt((Ax * Ax) + (Ay * Ay) + (Az * Az)) - 1.0);

  if (aux_Magnitud > MagnitudUmbral && aux_Magnitud > Magnitud )
  {
    Magnitud = aux_Magnitud;
    SerialBT.println((String)"lvl "+Magnitud*40);
    SerialBT.println((String)"plot "+Magnitud*40);
    SerialBT.println((String)"txt "+Magnitud); 
    timeL = millis();
  }
  if (millis() - timeL > 1000)
  { 
    timeL = millis();
    ledState = !ledState;
    IMU_Temperature = ((float)mpu6050.getRawTemp()/333.87) + 11.0;        //340.0)+36.53; // You have to divide the temperature reading by 340 and then add +36.53.  The result is Celsius.
  //  SerialBT.println((String)"txt "+IMU_Temperature); 
    SerialBT.println(ledState ? "pled 1\n" : "pled 0\n");//+ledState);
    SerialBT.println((String)"lvl "+MagnitudUmbral*40); 
    Magnitud = 0;     
  }
  if (millis() - timeS > 100)
  { 
    SerialBT.println((String)"plot "+(aux_Magnitud*40));      
    timeS = millis();    
  }
  
  if (SerialBT.available()) 
  {
    Serial.write(SerialBT.read());
  }
}

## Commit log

2019-07-19 agregué esquema de conexiones
    [papatronica.fzz]
2019-07-19 corregí modelo de nodeMCU
    [componentes.csv]
2019-08-08 Este archivo es para poder crear la nueva carpeta solamente
2019-08-08 Versión 5
    [Carcaza Papa - MH.STL, Carcaza Papa - MH.sldprt, Carcaza Papa - MR.SLDPRT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]
2019-10-03 Archivos de Solidworks
    [v6 - Carcaza Papa - MH.sldprt, v6 - Carcaza Papa - MR.sldprt, v6 - Carcaza Papa - Rejilla.sldprt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]
2019-10-03 Archivos STL
    Archivos STL listos para ser sliceados
    [v6 - Carcaza Papa - MH.STL, v6 - Carcaza Papa - MR.STL, v6 - Carcaza Papa - Rejilla.STL]
2019-11-26 Instrucciones
    Instrucciones y gcode para la impresión en la impresora 3D Max
2019-11-26 Agregado de brim
    En base a la impresión de esta pieza del dia 26-11-19 se agrego brim a la pieza para evitar el levantamiento o separación de la cama
2020-01-23 Version 7
    Rediseño de la carcasa con nuevas operaciones y nombres de operaciones más claros.
    Los .gcode incluidos están echos para la impresora Createbot MAX 3D Printer y deben ser modificados para usar en otras impresora. Los Gcode incluyen las configuraciones usadas por el Slic3r aunque so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
    Se incluyen videos y PDFs (3D PDF) del diseño, para los PDFs es necesario usar un lector capaz de abrir contenido 3D en PDF
    [v7 - Carcasa Papatronica - Ensamble Completo.SLDASM, v7 - Carcasa Papatronica - Mitad Tornillos.STL, v7 - Carcasa Papatronica - Mitad Tornillos.sldprt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]
2023-02-15 Se sube las versiones poliedricas de las carcasas
    [carcasa-tornillos-poliedrica.stl, carcasa-tuercas-poliedrica.stl]
2023-03-13 v8, sin soportes.
    [v8 - Carcasa Papatronica - Mitad Tornillos.STL, v8 - Carcasa Papatronica - Mitad Tuercas.STL, v8 - Carcasa Papatronica - Rejilla.STL]
